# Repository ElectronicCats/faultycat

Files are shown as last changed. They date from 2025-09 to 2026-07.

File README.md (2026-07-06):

# Faulty Cat

> ## Firmware and host tools have moved
>
> This repository now holds the **hardware design** only. The
> firmware (v2, a from-scratch rewrite for the existing FaultyCat
> v2.x hardware) has moved to
> [FaultyCat-Firmware](https://github.com/ElectronicCats/FaultyCat-Firmware),
> and the Python host CLI/TUI (`faultycmd`) has moved to
> [faultycat-TUI](https://github.com/ElectronicCats/faultycat-TUI/).
> See the **Firmware Repository** and **Python Tools Repository**
> sections below.

Faulty Cat is a low-cost Electromagnetic Fault Injection (EMFI) tool, designed specifically for self-study and hobbiest research.

<a href="https://github.com/ElectronicCats/FaultyCat/wiki">
  <p align="center">
  
    </p>
</a>

<p align=center>
<a href="https://electroniccats.com/store/faulty-cat/">
  
</a>

<a href="https://github.com/ElectronicCats/faultycat/wiki">
  
</a>
</p>

<p align=center>
  Also available at distributors:
</p>
<p align=center>
  <a href="https://labs.ksec.co.uk/product-category/electronic-cat/">
    
  </a>
</p>

Faulty Cat is a high-end Electromagnetic Fault Injection (EMFI) tool a remix of the project [ChipSHOUTER PicoEMP](https://github.com/newaetech/chipshouter-picoemp) design optimization focused in rough order on (1) safe operation, (2) high performance, (3) usability, and finally (4) cost. This results in a tool that covers many use-cases, but may be overkill (and expensive) for many.

> **How the glitching works.** Firmware v3 ships two physical
> fault-injection techniques — **EMFI** (electromagnetic) and
> **Crowbar** (voltage glitching) — each available as **direct**
> single-shot fires or as parameter-swept **Campaigns**. For the
> full breakdown of what each engine does, the parameter matrix
> that differentiates them, and how the four combinations are
> driven from the host tool, see `docs/GLITCHING.md` in the
> [firmware repository](https://github.com/ElectronicCats/FaultyCat-Firmware).

We have created this project in KiCad and looking for alternatives to some components, we have left aside the Raspberry Pico board to use the RP2040 directly in the design. Tested in our laboratory before going on sale, even so, it is a product that must be handled with care, read the instructions for use.

Please **only** use Faulty Cat when you have purchased it from us and control it yourself, with full knowledge of the operation and risks. It is *not* designed for use in professional or educational environments, where tools are expected to meet safety certifications.

**IMPORTANT**: The plastic shield is critical for safe operation. While the output itself is isolated from the input connections, you will still **easily shock yourself** on the exposed high-voltage capacitor and circuitry. **NEVER** operate the device without the shield.

As an open-source project and as a remix of the project [ChipSHOUTER PicoEMP](https://github.com/newaetech/chipshouter-picoemp), it also collects inputs from various community members, and welcomes your contributions!

###  NEW FEATURES AVAILABLE ON V2.1⚡😼

- Voltage glitching.
- Trigger using dedicated pins, available in the new pinout.
- Trigger voltage reference, for more accurate response every time a voltage glitch is attempted to be sent.
- Analog input to monitor the target device’s status during the glitching process.
- JTAG/SWD scanner. **(Firmware v3.0 status: `scan swd` is the only
  scanner verb publicly exposed. JTAG scan, direct JTAG verbs, and
  direct SWD verbs are gated as WIP for v3.1 — see
  `docs/JTAG_INTERNALS.md` in the
  [firmware repository](https://github.com/ElectronicCats/FaultyCat-Firmware)
  for the details.)**

### Two attack engines (EMFI and Crowbar)

Firmware v3 exposes two physical fault-injection techniques (EMFI
and Crowbar voltage glitching) and two operational modes (direct
single-shot fires and Campaign parameter sweeps over delay/width/
power). They compose freely — both engines work in both modes.
The full matrix, wire-protocol routing, and host-CLI map live in
`docs/GLITCHING.md` in the
[firmware repository](https://github.com/ElectronicCats/FaultyCat-Firmware).

## Thanks / Contributors

Faulty Cat based in PicoEMP is a community-focused project, with major contributions from:
* Colin O'Flynn (original HW design, simple Python demo)
* [stacksmashing](https://twitter.com/ghidraninja) (C firmware for full PIO feature set)
* [Lennert Wouters](https://twitter.com/LennertWo) (C improvements, first real demo)
* [@nilswiersma](https://github.com/nilswiersma) (Triggering/C improvements)

## Firmware Repository

The FaultyCat firmware has been moved to a different repository, to
have a better version control, and issue tracking you will find it
here:

https://github.com/ElectronicCats/FaultyCat-Firmware

That repository covers building and flashing the firmware (BOOTSEL
button and magic-baud remote BOOTSEL paths), the release scheme, and
the full architecture / safety / glitching-engine documentation
(`docs/ARCHITECTURE.md`, `docs/SAFETY.md`, `docs/GLITCHING.md`,
`docs/JTAG_INTERNALS.md`, `docs/RELEASES.md`, etc.).

## Python Tools Repository

The `faultycmd` host CLI/TUI has been moved to a different
repository, to have a better version control, and issue tracking you
will find it here:

https://github.com/ElectronicCats/faultycat-TUI/

That repository covers installing and using `faultycmd` (venv setup
on Linux, Windows, macOS, hotkeys, trigger polarity, trigger
timeout).

### Useful References

If you don't know where to start with Electromagnetic Fault Injection (EMFI), you may find a couple of chapters of the [Hardware Hacking Handbook](https://nostarch.com/hardwarehacking) useful.

You can see a demo of PicoEMP being used on a real attack in this [TI CC SimpleLink attack demo](https://github.com/KULeuven-COSIC/SimpleLink-FI/blob/main/notebooks/5_ChipSHOUTER-PicoEMP.ipynb).

**WARNING**: The high voltage will be applied across the SMA connector. If an injection tip (coil) is present, it will absorb most of the power. If you leave the SMA connector open, you will present a high voltage pulse across this SMA and could shock yourself. Do NOT touch the output SMA tip as a general "best practice", and treat the output as if it has a high voltage present.

## How to contribute 
 Contributions are welcome!

Please read the document  [**Contribution Manual**](https://github.com/ElectronicCats/electroniccats-cla/blob/main/electroniccats-contribution-manual.md)  which will show you how to contribute your changes to the project.

✨ Thanks to all our [contributors](https://github.com/ElectronicCats/faultycat/graphs/contributors)! ✨

See [**_Electronic Cats CLA_**](https://github.com/ElectronicCats/electroniccats-cla/blob/main/electroniccats-cla.md) for more information.

See the  [**community code of conduct**](https://github.com/ElectronicCats/electroniccats-cla/blob/main/electroniccats-community-code-of-conduct.md) for a vision of the community we want to build and what we expect from it.

## License

This project FaultyCat is adapted from [ChipSHOUTER PicoEMP](https://github.com/newaetech/chipshouter-picoemp) by [Colin O'Flynn](https://github.com/colinoflynn) is licensed under CC BY-SA 3.0, "FaultyCat" contains modifications such as: porting the project to Kicad, modifying BOM and dimensions is licensed under CC BY-SA 3.0 by ElectronicCats.

Electronic Cats invests time and resources in providing this open-source design. Please support Electronic Cats and open-source hardware by purchasing products from Electronic Cats!

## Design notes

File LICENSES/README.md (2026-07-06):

# LICENSES/

This directory holds:

## The hardware itself

The FaultyCat **hardware** (KiCad project under `/Hardware/`) is
licensed under **CC BY-SA 3.0** by Electronic Cats, as a remix of
ChipSHOUTER PicoEMP by Colin O'Flynn. That license covers the
KiCad/PCB files only; it does **not** apply to the firmware in this
repository, which is BSD-3-Clause.

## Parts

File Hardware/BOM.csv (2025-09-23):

Reference | Value | Datasheet | Footprint | Qty | DNP | LCSC# | Manf# | Proveedor
C1,C3 | 4.7uF |  | Capacitor_SMD:C_0805_2012Metric | 2 |  | C98192 | C2012X5R1H475K125AB | LCSC
C2 | 100nF |  | Capacitor_SMD:C_0603_1608Metric | 1 |  | C30926 | C0603C104K5RACTU | LCSC
C4 | 0.47uF |  | BuggyCat:CAPC6153X500N | 1 |  | C692326 | KRM55TR72J474MH01K | MOUSER
C5,C6 | 10uF |  | Capacitor_SMD:C_0402_1005Metric | 2 |  | C15525 | CL05A106MQ5NUNC | LCSC
C7,C11,C12,C14,C15,C16,C17,C18,C19,C20 | 100nF |  | Capacitor_SMD:C_0402_1005Metric | 10 |  | C131394 |  | LCSC
C8,C10 | 27pF |  | Capacitor_SMD:C_0603_1608Metric | 2 |  | C107045 | C0603C270J5GAC7411 | LCSC
C9,C13 | 1uF |  | Capacitor_SMD:C_0603_1608Metric | 2 |  | C26413 | CL10A105KP8NNNC | LCSC
C21,C22 | 100nF |  | Capacitor_SMD:C_0603_1608Metric | 2 |  | C14663 |  | LCSC
D1,D2,D3,D10 | SM4005PL-TP | https://www.mouser.mx/datasheet/2/258/SM4001PL_SM4007PL_SOD_123FL_-2511365.pdf | Diode_SMD:D_SOD-123F | 4 |  | C437593 | 1N4005 | MOUSER
D4 | MURA160T3G | https://www.diodes.com/assets/Datasheets/ds16008.pdf | Diode_SMD:D_SMA | 1 |  | C85095 | US1J-13-F | MOUSER
D5 | MM3Zxx | https://www.mouser.mx/datasheet/2/308/1/MM3Z9V1B_D-1811445.pdf | Diode_SMD:D_SOD-323F | 1 |  | C263147 | MM3Z18VB | MOUSER
D6 | MBR120 | http://www.onsemi.com/pub_link/Collateral/MBR340-D.PDF | Diode_SMD:D_SOD-123 | 1 |  | C130880 |  | LCSC
D7 | H.V.Detected | https://www.mouser.mx/ProductDetail/Kingbright/APT1608SECK?qs=SxaZfIVsCL3ll9vpt7nTCw%3D%3D | LED_SMD:LED_0603_1608Metric | 1 |  | C157740 | APT1608SECK | LCSC
D8 | Status | https://www.mouser.mx/datasheet/2/216/APT1608CGCK-24002.pdf | LED_SMD:LED_0603_1608Metric | 1 |  | C192666 | APT1608CGCK | LCSC
D9 | Charge On | https://www.mouser.mx/ProductDetail/Kingbright/APT1608SECK?qs=SxaZfIVsCL3ll9vpt7nTCw%3D%3D | LED_SMD:LED_0603_1608Metric | 1 |  | C157740 | APT1608SECK | LCSC
F1 | 0.5A | https://www.mouser.mx/datasheet/2/427/mfuserie-1762582.pdf | Fuse:Fuse_0805_2012Metric | 1 |  | C2649565 | MFU0805FF00500P100 | LCSC
J1 | Antenna | https://www.mouser.mx/datasheet/2/276/3/0732511150_RF_COAX_CONNECTORS-2847622.pdf | BuggyCat:732511150 | 1 |  |  | 73251-1150 | MOUSER
J2 | BG306-02-A-2-0400-L-G | https://www.mouser.mx/datasheet/2/837/BG306-1948788.pdf | BuggyCat:BG30602A20400LG | 1 |  |  | BG306-02-A-2-0400-L-G | MOUSER
J3 | Conn_01x10 | ~ | Connector_PinSocket_2.54mm:PinSocket_1x10_P2.54mm_Vertical | 1 |  | C5116489 | 10-PIN
J4 | Header 2 | ~ | Connector_PinHeader_2.54mm:PinHeader_1x02_P2.54mm_Vertical | 1 | DNP
J5 | Header 4 | ~ | Connector_PinHeader_2.54mm:PinHeader_1x04_P2.54mm_Vertical | 1 | DNP
J6 | Input Power:2x AA Battery | ~ | Connector_PinHeader_2.54mm:PinHeader_1x02_P2.54mm_Vertical | 1 | DNP
J7 | GLITCHER_EN | ~ | Connector_PinSocket_2.54mm:PinSocket_1x02_P2.54mm_Vertical | 1 |  | C7499322 | 2-PIN
J8 | ANALOG_PINS | ~ | Connector_PinSocket_2.54mm:PinSocket_1x02_P2.54mm_Vertical | 1 |  | C7499322 | 2-PIN
J9 | TRIGGER_IN | ~ | Connector_PinSocket_2.54mm:PinSocket_1x02_P2.54mm_Vertical | 1 |  | C7499322 | 2-PIN
J10 | TRIGGER_VREF | ~ | Connector_PinSocket_2.54mm:PinSocket_1x02_P2.54mm_Vertical | 1 |  | C7499322 | 2-PIN
P1 | USB_C_Plug_USB2.0 | https://www.usb.org/sites/default/files/documents/usb_type-c.zip | Connectors:C393939 | 1 |  | C393939 |  | LCSC
Q1,Q2 | AO3422 | http://www.aosmd.com/pdfs/datasheet/AO3400A.pdf | Package_TO_SOT_SMD:SOT-23 | 2 |  | C37130 | AO3422 | Digikey
Q3 | LDA111STR | https://www.mouser.mx/datasheet/2/240/LDA111-1547747.pdf | BuggyCat:SOP254P952X470-6N | 1 |  |  | LDA111STR | MOUSER
Q4 | RGT16BM65DTL | https://fscdn.rohm.com/en/products/databook/datasheet/discrete/igbt/rgt16bm65d-e.pdf | Package_TO_SOT_SMD:TO-252-3_TabPin2 | 1 |  | C3193927 | RGT16BM65DTL | MOUSER
Q5 | DMG3415U-7 | https://www.mouser.mx/datasheet/2/115/ds31735-64958.pdf | Package_TO_SOT_SMD:SOT-23 | 1 |  | C96616 | DMG3415U-7 | LCSC
Q7 | IRLML2502 |  | Package_TO_SOT_SMD:SOT-23 | 1 |  | C5364308 |  | LCSC
Q8 | IRF7807PBF |  | BuggyCat:SOIC-8_SI | 1 |  | C142600 |  | LCSC
R1,R9 | 10R |  | Resistor_SMD:R_0603_1608Metric | 2 |  | C109318 | RC0603FR-0710RL | LCSC
R2,R4 | 5.1K |  | Resistor_SMD:R_0603_1608Metric | 2 |  | C23186 | CRCW06035K10FKEAC | LCSC
R3 | 75R |  | Resistor_SMD:R_0805_2012Metric | 1 |  | C141697 | RC0805FR-0775RL | LCSC
R5,R6,R13,R14,R16 | 1K |  | Resistor_SMD:R_0603_1608Metric | 5 |  | C22548 | RC0603FR-071KL | LCSC
R7 | 22K |  | Resistor_SMD:R_0603_1608Metric | 1 |  | C114065 | RC0603FR-0722KL | LCSC
R8 | 2K |  | Resistor_SMD:R_0805_2012Metric | 1 |  | C114572 | RC0805FR-072KL | LCSC
R10 | 20M |  | Resistor_SMD:R_2010_5025Metric | 1 |  |  | CRMA2010AF20M0FKEF | MOUSER
R11 | 300K |  | BuggyCat:RESC6432X120N | 1 |  |  | 3522300KFT | MOUSER
R12 | 100K |  | Resistor_SMD:R_0603_1608Metric | 1 |  | C100048 |  | LCSC
R15 | 4.7k | ~ | Resistor_SMD:R_0603_1608Metric | 1 |  | C116697 |  | LCSC
R17,R25,R26 | 10K |  | Resistor_SMD:R_0603_1608Metric | 3 |  | C103199 |  | LCSC
R18 | 1k |  | Resistor_SMD:R_0603_1608Metric | 1 |  | C115325 |  | LCSC
R19,R20 | 27 |  | Resistor_SMD:R_0603_1608Metric | 2 |  | C25224 | ERJ-3GEYJ270V | MOUSER
R21 | 10k | ~ | Resistor_SMD:R_0603_1608Metric | 1 |  | C103199 |  | LCSC
R23,R24 | 1R | ~ | Resistor_SMD:R_0603_1608Metric | 2 |  | C140111 |  | LCSC
SW1,SW3,SW6 | TL3305AF260QG | https://www.mouser.mx/datasheet/2/140/TL3305-2065758.pdf | BuggyCat:TL3305AF160QG | 3 |  | C2886902 | TL3305AF260QG | MOUSER
SW2 | ON | https://www.mouser.mx/datasheet/2/240/js-3050885.pdf | chipshouter:OS102011MA1QN1 | 1 |  | C221829 | OS102011MS2QN1 | MOUSER
SW4 | RESET | https://www.mouser.mx/datasheet/2/140/TL3342-2065746.pdf | Button_Switch_SMD:SW_SPST_TL3342 | 1 |  | C318889 | TL3342F450QG | MOUSER
SW5 | BOOT | https://www.mouser.mx/datasheet/2/140/TL3342-2065746.pdf | Button_Switch_SMD:SW_SPST_TL3342 | 1 |  | C318889 | TL3342F450QG | MOUSER
SW7 | SW_SP3T | ~ | BuggyCat:Sw3P1T | 1 |  | C361168 |  | LCSC
T1,T2 | ATB322524 | ~ | BuggyCat:ATB3225240110T000 | 2 |  | C249001 | ATB322524-0110-T000 | MOUSER
U1 | AP2112K-3.3 | https://www.diodes.com/assets/Datasheets/AP7347DQ.pdf | Package_TO_SOT_SMD:SOT-23-5 | 1 |  | C216640 | AP7347DQ-33W5-7 | MOUSER
U2 | W25Q16JV | https://www.mouser.mx/datasheet/2/949/w25q16jv_spi_revg_03222018_plus-1489727.pdf | BuggyCat:W25Q16JVUUIQ | 1 |  |  | W25Q16JVUUIQ TR | MOUSER
U3 | RP2040 | https://www.mouser.mx/datasheet/2/630/hardware_design_with_rp2040-2904726.pdf | BuggyCat:RP2040-QFN-56 | 1 |  | C2040 | RPI Chip RP2040-7-500 | LCSC
U4 | TXS0108EPW | www.ti.com/lit/ds/symlink/txs0108e.pdf | Package_SO:TSSOP-20_4.4x6.5mm_P0.65mm | 1 |  | C1021790 |  | LCSC
U5 | TLV75718PDBV | https://www.ti.com/lit/ds/symlink/tlv757p.pdf | Package_TO_SOT_SMD:SOT-23-5 | 1 |  | C507270 |  | LCSC
U6 | SN74LVC1T45DBV | http://www.ti.com/lit/ds/symlink/sn74lvc1t45.pdf | Package_TO_SOT_SMD:SOT-23-6 | 1 |  | C7843 |  | LCSC
Y1 | 12Mhz | https://www.mouser.mx/datasheet/2/96/008-0360-0-786290.pdf | Crystal:Crystal_SMD_5032-2Pin_5.0x3.2mm | 1 |  |  | 445I23D12M00000 | MOUSER

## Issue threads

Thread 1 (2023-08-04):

License Violations

colinoflynn, 2023-08-04:
Hello - this project is currently in violation of CC-SA-3.0 license that PicoEMP is released under and this project heavily remixed. Please rectify this ASAP.

The license requires you to:

Attribution — You must give [appropriate credit](https://creativecommons.org/licenses/by-sa/3.0/#), provide a link to the license, and [indicate if changes were made](https://creativecommons.org/licenses/by-sa/3.0/#). You may do so in any reasonable manner, but not in any way that suggests the licensor endorses you or your use.

ShareAlike — If you remix, transform, or build upon the material, you must distribute your contributions under the [same license](https://creativecommons.org/licenses/by-sa/3.0/#) as the original.

The biggest issue here is reusing the majority of the text in the description without correctly attributing back to PicoEMP, along with similar issues on design (at least design is more of a remix than direct copy). But the remix of PicoEMP into FaultyCat should be a clear step, but it's very muddled right now. The remixed material should be shared under the same license per CC-SA-3.0.

This is required as it's possible/likely that FaultyCat is itself remixed in the future, and if that happens someone may not realize they were actually borrowing from PicoEMP. The link between all the projects should be clear for future users.

Thanks!

sabas1080, 2023-08-04:
Hello @colinoflynn

First of all, apologies for not executing the license correctly. We want to clarify that our intention was not to take the project's appropriation, we have made the corresponding changes, and we await your feedback.
Thank you so much for doing this great project. We admire your work and hope you like the changes we have made and the next ones we make to your project.

Best regards,

colinoflynn, 2023-08-04:
Thanks for quick fix, appreciate it & keeping the sharing spirit of FOSS alive! Looks like a nice mix (and no more broken battery wires ;-) ), hope you get a chance to let people enjoy EMFI at DC!

Closed 2023-08-04.

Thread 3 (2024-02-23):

Add schematic in pdf too

mrx23dot, 2024-02-23:

Marcelol52, 2024-02-23:
Hi, we will consider adding the file to the Wiki for later revisions. We cannot add it on the repository because it is not a binnary file and it would not be updated automatically by git. You can always check the schematics usig KiCAD on any operating system from the files found on the hardware section of the repository. I have shared the PDF with you attached in this message. Thank your for your suggestion and your preference.

[FaultyCat.pdf](https://github.com/ElectronicCats/faultycat/files/14388274/FaultyCat.pdf)

Closed 2024-02-23.

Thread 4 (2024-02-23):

Details on differences from PicoEMP

mrx23dot, 2024-02-23:
From current description it's not clear enough what are the benefits compared to PicoEMP:

 (1) safe operation, (2) high performance, (3) usability, and finally (4) cost.

e.g. how pulse is different.

Also how it's optimized for cost when price is 2x of PicoEMP

xpeqex, 2024-02-23:
Hi @mrx23dot

Thank you for the feedback. While FaultyCat is based on PicoEMP we were looking on improving the product itself.

In any case, I agree that more information should be added to better clarify the improvements in FaultyCat.

Here is a short description to the points you are mentioning that will be later updated in the wiki:
1. **_Safe operation_**. This refers to the use of commands to remotely operate FaultyCat, the enclosure that protects the user from a discharge of high-power components and the automatic shutdown function.
2. **_High Performance_**. Unlike other EMFI tools, FultyCat allows you to trigger the EMFI with a shorter charging time, using only three AA batteries and with a high voltage output through the _business end_, around 200V according to our tests.
3. **_Usability_** . FaultyCat **is a plug and play device, no need to solder and with firmware preloaded**. In any case, we work to provide further documentation and support. So you do not have only a product but a service too backing FaultyCat.
4. **_Cost_** . It is important to highlight the performance of FaultyCat against other EMFI device and the fact we take care of all the details of the board, from the manufacture process, testing to the provide support.

With this being said, FaultyCat as PicoEMP is an open source project, meaning that anyone can use the available information to improve and/or modify the product itself creating a more specialized product that fits your needs.

Hope this information is helpful. Be assure we will add this to our documentation, thank you for brining it to our attention.

Feel free to share with us any other feedback or queries!

Closed 2024-02-23.

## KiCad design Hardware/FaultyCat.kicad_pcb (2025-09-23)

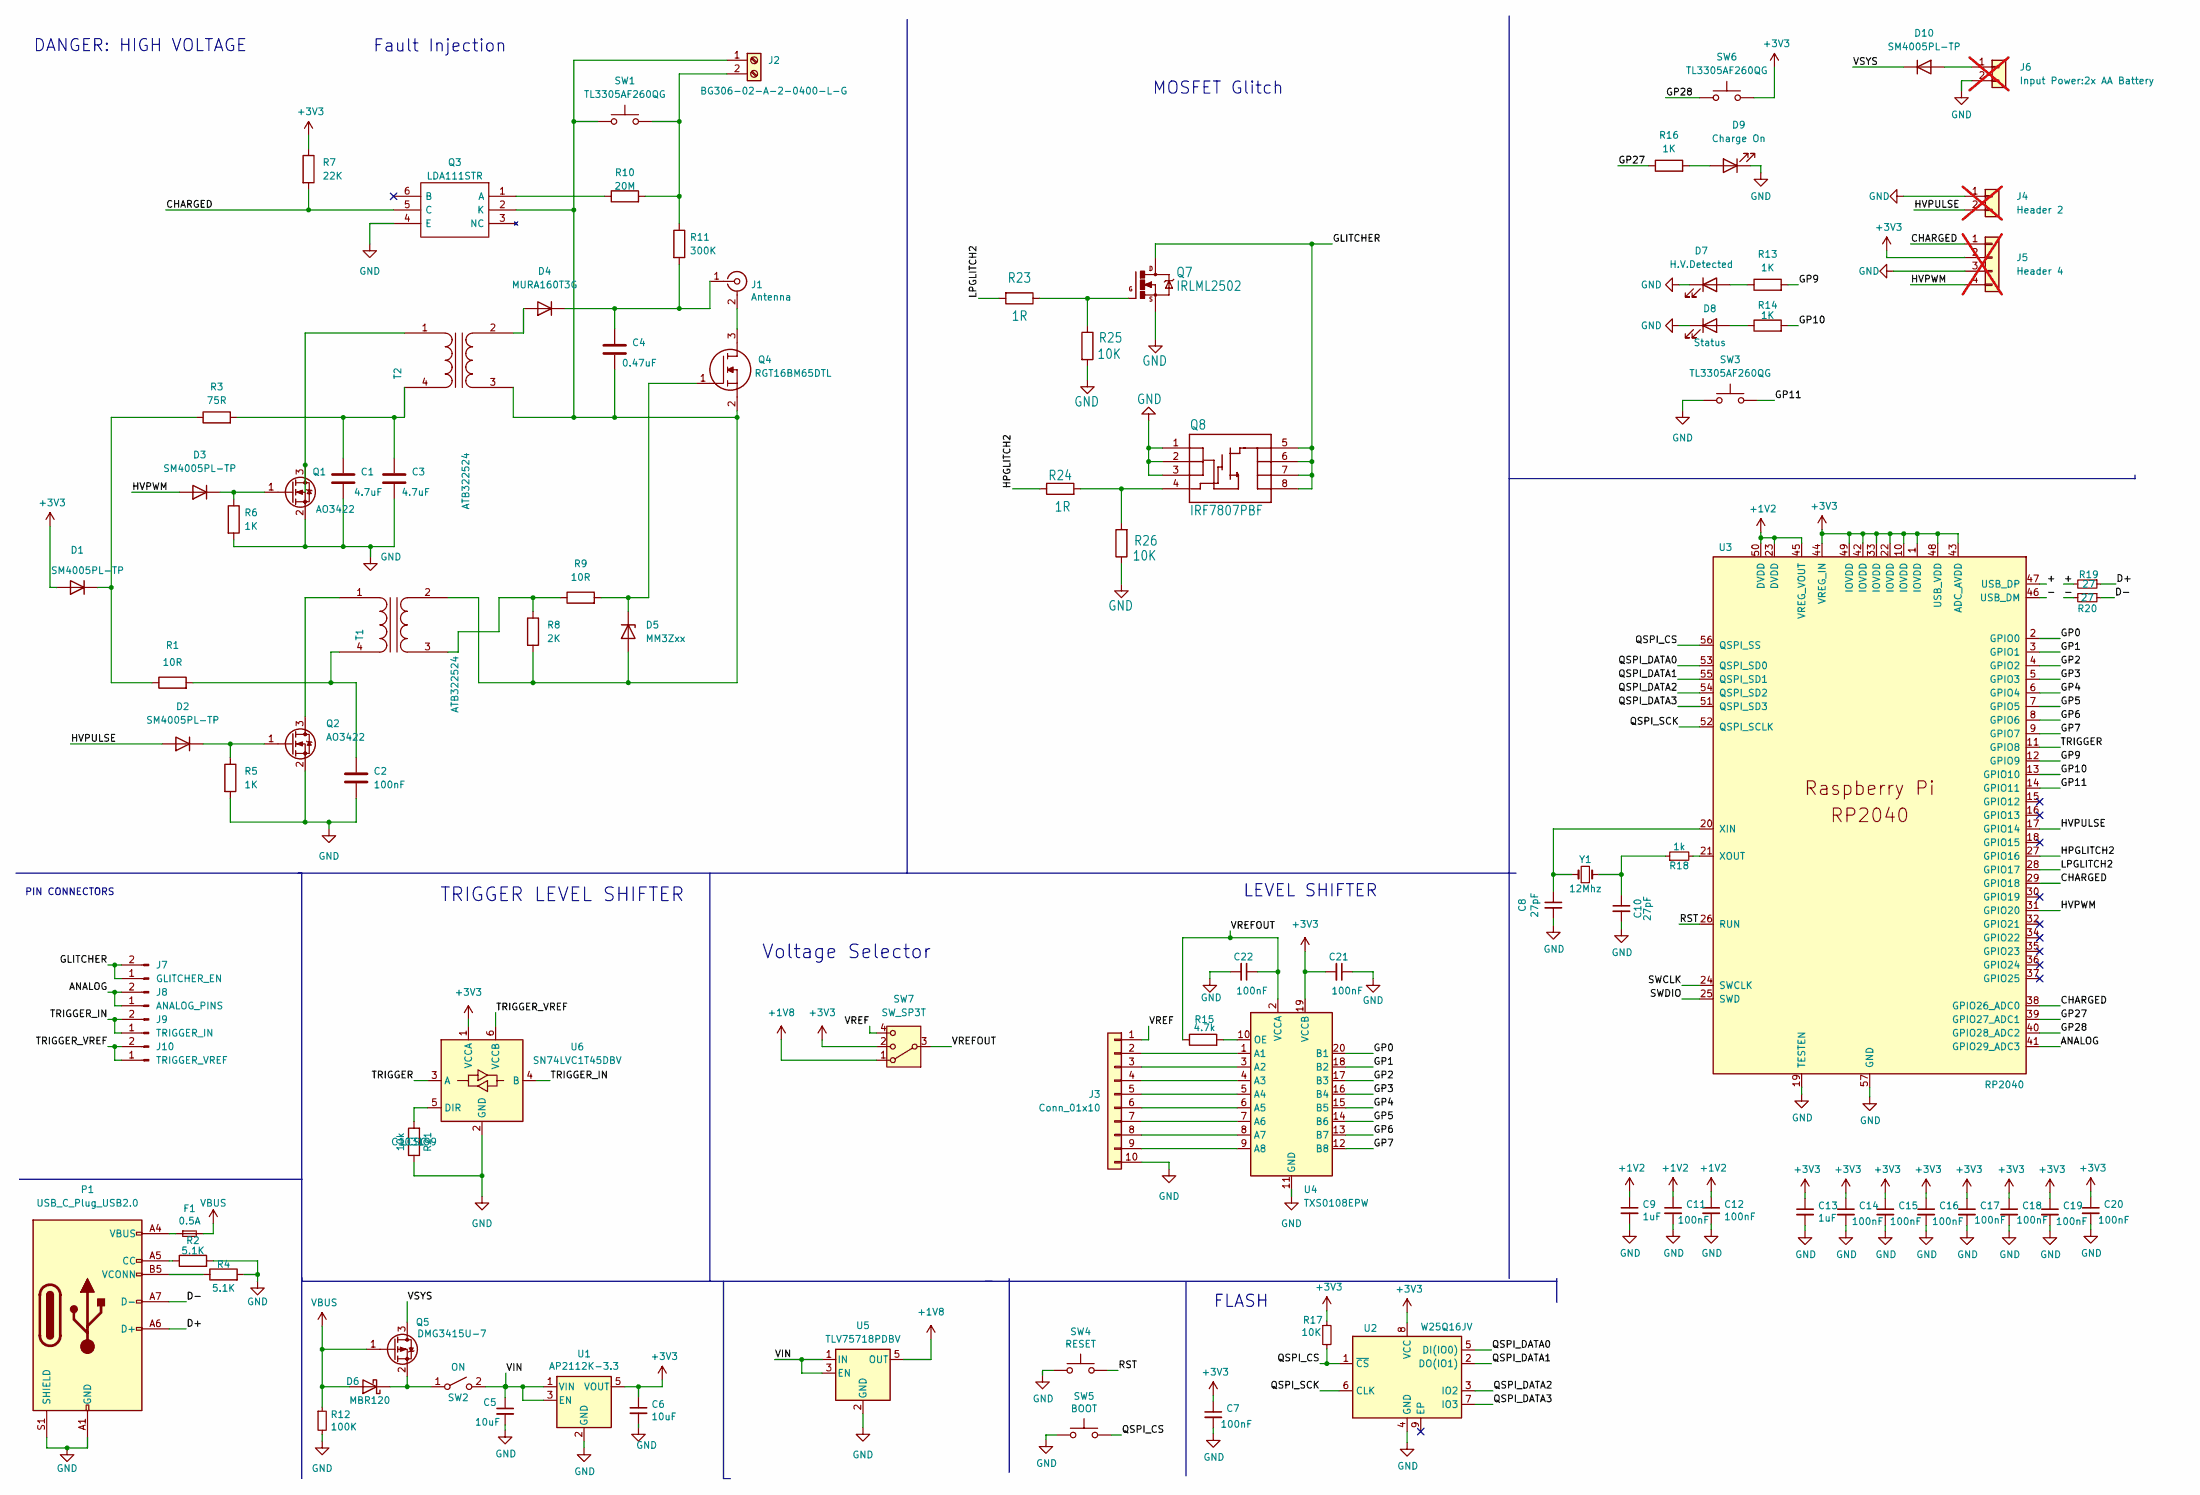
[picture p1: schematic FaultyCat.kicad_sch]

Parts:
C1, C3: 4.7uF; C_0805_2012Metric; LCSC# C98192
C2: 100nF; C_0603_1608Metric; LCSC# C30926
C4: 0.47uF; CAPC6153X500N; LCSC# C692326
C5, C6: 10uF; C_0402_1005Metric; LCSC# C15525
C7, C11, C12, C14, C15, C16, C17, C18, C19, C20: 100nF; C_0402_1005Metric; LCSC# C131394
C8, C10: 27pF; C_0603_1608Metric; LCSC# C107045
C9, C13: 1uF; C_0603_1608Metric; LCSC# C26413
C21, C22: 100nF; C_0603_1608Metric; LCSC# C14663
D1, D2, D3, D10: SM4005PL-TP; D_SOD-123F; LCSC# C437593
D4: MURA160T3G; D_SMA; LCSC# C85095
D5: MM3Zxx; D_SOD-323F; LCSC# C263147
D6: MBR120; D_SOD-123; LCSC# C130880
D7: H.V.Detected; LED_0603_1608Metric; LCSC# C157740
D8: Status; LED_0603_1608Metric; LCSC# C192666
D9: Charge On; LED_0603_1608Metric; LCSC# C157740
F1: 0.5A; Fuse_0805_2012Metric; LCSC# C2649565
J1: Antenna; 732511150
J2: BG306-02-A-2-0400-L-G; BG30602A20400LG
J3: Conn_01x10; PinSocket_1x10_P2.54mm_Vertical; LCSC# C5116489
J4: Header 2; PinHeader_1x02_P2.54mm_Vertical; not fitted
J5: Header 4; PinHeader_1x04_P2.54mm_Vertical; not fitted
J6: Input Power:2x AA Battery; PinHeader_1x02_P2.54mm_Vertical; not fitted
J7: GLITCHER_EN; PinSocket_1x02_P2.54mm_Vertical; LCSC# C7499322
J8: ANALOG_PINS; PinSocket_1x02_P2.54mm_Vertical; LCSC# C7499322
J9: TRIGGER_IN; PinSocket_1x02_P2.54mm_Vertical; LCSC# C7499322
J10: TRIGGER_VREF; PinSocket_1x02_P2.54mm_Vertical; LCSC# C7499322
P1: USB_C_Plug_USB2.0; C393939; LCSC# C393939
Q1, Q2: AO3422; SOT-23; LCSC# C37130
Q3: LDA111STR; SOP254P952X470-6N
Q4: RGT16BM65DTL; TO-252-3_TabPin2; LCSC# C3193927
Q5: DMG3415U-7; SOT-23; LCSC# C96616
Q7: IRLML2502; SOT-23; LCSC# C5364308
Q8: IRF7807PBF; SOIC-8_SI; LCSC# C142600
R1, R9: 10R; R_0603_1608Metric; LCSC# C109318
R2, R4: 5.1K; R_0603_1608Metric; LCSC# C23186
R3: 75R; R_0805_2012Metric; LCSC# C141697
R5, R6, R13, R14, R16: 1K; R_0603_1608Metric; LCSC# C22548
R7: 22K; R_0603_1608Metric; LCSC# C114065
R8: 2K; R_0805_2012Metric; LCSC# C114572
R10: 20M; R_2010_5025Metric
R11: 300K; RESC6432X120N
R12: 100K; R_0603_1608Metric; LCSC# C100048
R15: 4.7k; R_0603_1608Metric; LCSC# C116697
R17, R25, R26: 10K; R_0603_1608Metric; LCSC# C103199
R18: 1k; R_0603_1608Metric; LCSC# C115325
R19, R20: 27; R_0603_1608Metric; LCSC# C25224
R21: 10k; R_0603_1608Metric; LCSC# C103199
R23, R24: 1R; R_0603_1608Metric; LCSC# C140111
SW1, SW3, SW6: TL3305AF260QG; TL3305AF160QG; LCSC# C2886902
SW2: ON; OS102011MA1QN1; LCSC# C221829
SW4: RESET; SW_SPST_TL3342; LCSC# C318889
SW5: BOOT; SW_SPST_TL3342; LCSC# C318889
SW7: SW_SP3T; Sw3P1T; LCSC# C361168
T1, T2: ATB322524; ATB3225240110T000; LCSC# C249001
U1: AP2112K-3.3; SOT-23-5; LCSC# C216640
U2: W25Q16JV; W25Q16JVUUIQ
U3: RP2040; RP2040-QFN-56; LCSC# C2040
U4: TXS0108EPW; TSSOP-20_4.4x6.5mm_P0.65mm; LCSC# C1021790
U5: TLV75718PDBV; SOT-23-5; LCSC# C507270
U6: SN74LVC1T45DBV; SOT-23-6; LCSC# C7843
Y1: 12Mhz; Crystal_SMD_5032-2Pin_5.0x3.2mm

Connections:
+1V2: C9.1, C11.1, C12.1, U3.23 (DVDD), U3.45 (VREG_VOUT), U3.50 (DVDD)
+1V8: SW7.1, U5.5 (OUT); also elsewhere on the board
+3V3: C6.1, C7.1, C13.1, C14.1, C15.1, C16.1, C17.1, C18.1, C19.1, C20.1, C21.2, D1.2 (A), J5.2, R7.1, R17.1, SW6.2, SW7.2, U1.5 (VOUT), U2.8 (VCC), U3.1 (IOVDD), U3.10 (IOVDD), U3.22 (IOVDD), U3.33 (IOVDD), U3.42 (IOVDD), U3.43 (ADC_AVDD), U3.44 (VREG_IN), U3.48 (USB_VDD), U3.49 (IOVDD), U4.19 (VCCB), U6.1 (VCCA)
/+: R19.2, U3.47 (USB_DP)
/-: R20.2, U3.46 (USB_DM)
/ANALOG: J8.1, J8.2, U3.41 (GPIO29_ADC3)
/CHARGED: J5.1, Q3.5 (C), R7.2, U3.29 (GPIO18), U3.38 (GPIO26_ADC0)
/D+: P1.A6 (D+), R19.1
/D-: P1.A7 (D-), R20.1
/GLITCHER: J7.1, J7.2, Q7.3 (D), Q8.5 (D@4), Q8.6 (D@3), Q8.7 (D@2), Q8.8 (D@1)
/GP0: U3.2 (GPIO0), U4.20 (B1)
/GP1: U3.3 (GPIO1), U4.18 (B2)
/GP2: U3.4 (GPIO2), U4.17 (B3)
/GP3: U3.5 (GPIO3), U4.16 (B4)
/GP4: U3.6 (GPIO4), U4.15 (B5)
/GP5: U3.7 (GPIO5), U4.14 (B6)
/GP6: U3.8 (GPIO6), U4.13 (B7)
/GP7: U3.9 (GPIO7), U4.12 (B8)
/GP9: R13.2, U3.12 (GPIO9)
/GP10: R14.2, U3.13 (GPIO10)
/GP11: SW3.2, U3.14 (GPIO11)
/GP27: R16.1, U3.39 (GPIO27_ADC1)
/GP28: SW6.1, U3.40 (GPIO28_ADC2)
/HPGLITCH2: R24.1, U3.27 (GPIO16)
/HVPULSE: D2.2 (A), J4.2, U3.17 (GPIO14)
/HVPWM: D3.2 (A), J5.4, U3.31 (GPIO20)
/LPGLITCH2: R23.2, U3.28 (GPIO17)
/QSPI_CS: R17.2, SW5.2, U2.1 (~CS), U3.56 (QSPI_SS)
/QSPI_DATA0: U2.5 (DI(IO0)), U3.53 (QSPI_SD0)
/QSPI_DATA1: U2.2 (DO(IO1)), U3.55 (QSPI_SD1)
/QSPI_DATA2: U2.3 (IO2), U3.54 (QSPI_SD2)
/QSPI_DATA3: U2.7 (IO3), U3.51 (QSPI_SD3)
/QSPI_SCK: U2.6 (CLK), U3.52 (QSPI_SCLK)
/RST: SW4.2, U3.26 (RUN)
/SWCLK: U3.24 (SWCLK)
/SWDIO: U3.25 (SWD)
/TRIGGER: U3.11 (GPIO8), U6.3 (A)
/TRIGGER_IN: J9.1, J9.2, U6.4 (B)
/TRIGGER_VREF: J10.1, J10.2, U6.6 (VCCB)
/VIN: C5.1, SW2.2 (B), U1.1 (VIN), U1.3 (EN), U5.1 (IN), U5.3 (EN); also elsewhere on the board
/VREF: J3.1, SW7.4
/VREFOUT: C22.1, R15.1, SW7.3, U4.2 (VCCA)
/VSYS: D10.1 (K), Q5.3 (D)
GND: C1.2, C2.2, C3.2, C5.2, C6.2, C7.2, C8.2, C9.2, C10.2, C11.2, C12.2, C13.2, C14.2, C15.2, C16.2, C17.2, C18.2, C19.2, C20.2, C21.1, C22.2, D7.1 (K), D8.1 (K), D9.1 (K), J3.10, J4.1, J5.3, J6.2, P1.A1 (GND), P1.A12 (GND), P1.B1 (GND), P1.B12 (GND), P1.S1 (SHIELD), Q1.2 (S), Q2.2 (S), Q3.4 (E), Q7.2 (S), Q8.1 (S@1), Q8.2 (S@2), Q8.3 (S@3), R2.2, R4.2, R5.2, R6.2, R12.2, R21.1, R25.2, R26.1, SW3.1, SW4.1, SW5.1, U1.2 (GND), U2.4 (GND), U3.19 (TESTEN), U3.57 (GND), U4.11 (GND), U5.2 (GND), U6.2 (GND); also elsewhere on the board
unnamed: C10.1, R18.1, Y1.2
unnamed: D1.1 (K), R1.1, R3.1
unnamed: D2.1 (K), Q2.1 (G), R5.1
unnamed: D3.1 (K), Q1.1 (G), R6.1
unnamed: D4.2 (A), T2.2 (SA)
unnamed: C4.1, D4.1 (K), J1.1 (In), R11.2
unnamed: C4.2, D5.2 (A), J2.1, Q3.2 (K), Q4.2, R8.2, SW1.1, T1.2 (SA), T2.3 (SB)
unnamed: D5.1 (K), Q4.1, R9.2
unnamed: D6.1 (K), Q5.2 (S), SW2.1 (A)
unnamed: D7.2 (A), R13.1
unnamed: D8.2 (A), R14.1
unnamed: D9.2 (A), R16.2
unnamed: D10.2 (A), J6.1
unnamed: F1.1, P1.A4 (VBUS), P1.A9 (VBUS), P1.B4 (VBUS), P1.B9 (VBUS)
unnamed: J1.2 (Ext), Q4.3
unnamed: J2.2, R10.2, R11.1, SW1.2
unnamed: J3.2, U4.1 (A1)
unnamed: J3.3, U4.3 (A2)
unnamed: J3.4, U4.4 (A3)
unnamed: J3.5, U4.5 (A4)
unnamed: J3.6, U4.6 (A5)
unnamed: J3.7, U4.7 (A6)
unnamed: J3.8, U4.8 (A7)
unnamed: J3.9, U4.9 (A8)
unnamed: P1.A5 (CC), R2.1
unnamed: P1.B5 (VCONN), R4.1
unnamed: Q1.3 (D), T2.1 (AB)
unnamed: Q2.3 (D), T1.1 (AB)
unnamed: Q3.1 (A), R10.1
unnamed: Q7.1 (G), R23.1, R25.1
unnamed: Q8.4 (G), R24.2, R26.2
unnamed: C2.1, R1.2, T1.4 (AA)
unnamed: R8.1, R9.1, T1.3 (SB)
unnamed: C1.1, C3.1, R3.2, T2.4 (AA)
unnamed: C8.1, U3.20 (XIN), Y1.1
unnamed: R18.2, U3.21 (XOUT)
unnamed: R15.2, U4.10 (OE)
unnamed: R21.2, U6.5 (DIR)
VBUS: D6.2 (A), F1.2, Q5.1 (G), R12.1

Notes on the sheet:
Voltage Selector
FLASH
TRIGGER LEVEL SHIFTER
MOSFET Glitch
DANGER: HIGH VOLTAGE
PIN CONNECTORS
LEVEL SHIFTER
Fault Injection

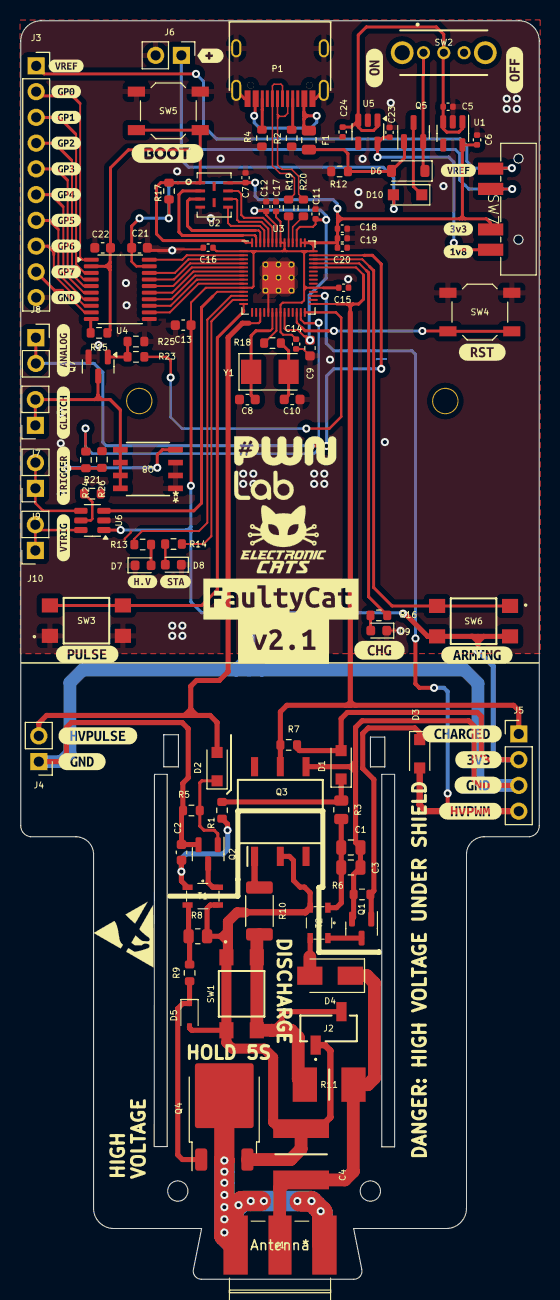
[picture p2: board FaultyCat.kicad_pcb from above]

Board: 2 copper layers, 51.2 x 124.2 mm, 129 parts (0 on the bottom side), 81 nets.

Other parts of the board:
C23, C24: 10uF; C_0402_1005Metric
kibuzzard-67A4D63C: G***; kibuzzard-67A4D63C
kibuzzard-67A4D65E: G***; kibuzzard-67A4D65E
kibuzzard-67A4D80D: G***; kibuzzard-67A4D80D
kibuzzard-67A4D86D: G***; kibuzzard-67A4D86D
kibuzzard-67A4D88F: G***; kibuzzard-67A4D88F
kibuzzard-67A4D93E: G***; kibuzzard-67A4D93E
kibuzzard-67A4D642: G***; kibuzzard-67A4D642
kibuzzard-67A4D648: G***; kibuzzard-67A4D648
kibuzzard-67A4D805: G***; kibuzzard-67A4D805
kibuzzard-67A4D873: G***; kibuzzard-67A4D873
kibuzzard-67A4D879: G***; kibuzzard-67A4D879
kibuzzard-67A4D880: G***; kibuzzard-67A4D880
kibuzzard-67A4D886: G***; kibuzzard-67A4D886
kibuzzard-67A4D896: G***; kibuzzard-67A4D896
kibuzzard-67AA52CA: G***; kibuzzard-67AA52CA
kibuzzard-67AA52D2: G***; kibuzzard-67AA52D2
kibuzzard-642DF5C4: G***; kibuzzard-642DF5C4
kibuzzard-642DF578: G***; kibuzzard-642DF578
kibuzzard-642E0AC9: G***; kibuzzard-642E0AC9
kibuzzard-642E0AD5: G***; kibuzzard-642E0AD5
kibuzzard-642E0AF5: G***; kibuzzard-642E0AF5
kibuzzard-642E0B26: G***; kibuzzard-642E0B26
kibuzzard-642E0B82: G***; kibuzzard-642E0B82
kibuzzard-642E0B91: G***; kibuzzard-642E0B91
kibuzzard-642E11AF: G***; kibuzzard-642E11AF
kibuzzard-642F0B74: G***; kibuzzard-642F0B74
kibuzzard-681E47A0: G***; kibuzzard-681E47A0
kibuzzard-681E47A5: G***; kibuzzard-681E47A5
kibuzzard-681E4798: G***; kibuzzard-681E4798
kibuzzard-6797D18C: G***; kibuzzard-6797D18C
kibuzzard-64767B55: G***; kibuzzard-64767B55
kibuzzard-68509CA3: G***; kibuzzard-68509CA3
kibuzzard-647546A8: G***; kibuzzard-647546A8
kibuzzard-647546B9: G***; kibuzzard-647546B9
kibuzzard-6475468D: G***; kibuzzard-6475468D

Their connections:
+1V8: C23.1; also elsewhere on the board
/VIN: C24.1; also elsewhere on the board
GND: C23.2, C24.2; also elsewhere on the board

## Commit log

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2023-04-03 Renaming of all files from chipshoutercat to buggycat
    [BuggyCat.kicad_pcb, BuggyCat.kicad_sch]
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2025-02-10 fix(hw): move labels
    [FaultyCat.kicad_pcb]
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2025-05-13 fix(hw): remove manuf# from P1
    [FaultyCat.kicad_sch]
2025-06-09 fix(hw): move components
    [FaultyCat.kicad_pcb]
2025-06-26 fix(hw): change switch orientation
    [FaultyCat.kicad_pcb]
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2026-04-23 docs(v3): ARCHITECTURE + HARDWARE_V2 + PORTING + README rewrite banner
    F0 commit 4/5. First-cut documentation with the data confirmed during
    F0 research (2026-04-23):
    docs/ARCHITECTURE.md
    Layered view of the v3 firmware (hal → drivers → services → usb →
    apps), USB composite table with all 16/16 endpoints accounted for,
    SWD-bus arbitration policy (finalized in F9), and how faultycmd-rs
    sits on top.
    docs/HARDWARE_V2.md
    Authoritative pinout map for FaultyCat HW v2.x (v2.2 is the shipped
    version; v2.1 → v2.2 changed labels only). Derived from
    firmware/c/board_config.h, glitcher.c, and the KiCad schematic.
    Key confirmations from the maintainer this session:
    * scann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
2026-04-23 docs(plan): consolidate F0 resolutions + add phase-tracking skill
    Post-F0 housekeeping. Does not belong to any of the 5 F0 commits and
    does not block the v3.0-f0 tag — but lands with F0 so the plan and
    the Claude-Code skill reflect the same reality.
    FAULTYCAT_REFACTOR_PLAN.md
    §1 clarification: HW v2.2 is the only production revision (v2.1 →
    v2.2 = label change only, no nets).
    §2 table correction: raspberrypi/debugprobe is MIT, not BSD-3, and
    hextreeio/faultier is verified "NONE" (all rights reserved) →
    reference-only, marked EXCLUDE_FROM_ALL.
    §12 rewritten as "Decisiones resueltas en F0 (2026-04-23)":
    every item now shows its resolved value (branch rewrite/v3,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
2026-04-23 fix(v3): F0 blink on GP10 (real STATUS LED on v2.x) — NOT GP25
    F0 hotfix, lands before the v3.0-f0 tag.
    Root cause: the legacy firmware/c/board_config.h declares
    `PIN_LED_STATUS = 25`, which is correct when targeting the Raspberry
    Pi Pico module (GP25 is the Pico's onboard LED). But FaultyCat v2.x
    mounts the RP2040 **directly** on its own PCB — there is no Pico
    module and GP25 is not routed to any LED. The initial F0 blink
    flashed fine but produced no visible output on a physical v2.2
    board (verified by the maintainer 2026-04-23).
    Fix:
    apps/faultycat_fw/main.c
    STATUS_LED_PIN 25 → 10. The real STATUS LED on v2.x is GP10.
    (Cross-check: firmware/c/glitcher/glitcher.c line 23 a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
2026-04-23 feat(F1): HAL gpio + time — portable API, RP2040 impl, native fakes, 10 unit tests
    F1 commit 2/4. Extracts a thin, portable HAL layer so drivers and apps
    never touch pico-sdk APIs directly, and gives us host-side fakes so
    unit tests run natively without any MCU.
    Headers (`hal/include/hal/`)
    gpio.h — init / put / get / set_pulls. Minimal surface; drive
    strength and alt-functions arrive when a driver asks for
    them in F2+.
    time.h — sleep_ms, now_ms, now_us. 32-bit counters (wrap at 49.7d /
    71.6m respectively) — longer horizons land when needed.
    pio.h dma.h adc.h pwm.h usb.h — placeholder headers that trip
    `#error` on include. Forces u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
2026-04-23 feat(F1): rewrite F0 blink on top of the HAL
    F1 commit 3/4.
    No longer includes pico/stdlib.h or calls gpio_init/gpio_set_dir/
    gpio_put/sleep_ms. The file now compiles against hal/gpio.h and
    hal/time.h only. This is the template for every future app: apps
    assemble services, services assemble drivers, drivers talk to the
    HAL. Nothing below the HAL reaches sideways into pico-sdk.
    apps/faultycat_fw/CMakeLists.txt
    target_link_libraries(faultycat PRIVATE pico_stdlib)
    → target_link_libraries(faultycat PRIVATE hal_rp2040)
    hal_rp2040 transitively pulls pico_stdlib and hardware_gpio.
    Verification:
    * arm-none-eabi-nm on main.c.o shows only hal_gpio_init,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
2026-04-23 ci(F1): add host-tests job alongside the UF2 build
    F1 commit 4/4 — closes F1 (pending the physical blink checkpoint).
    Workflow now runs two parallel jobs on every push to rewrite/v3 and
    on every PR:
    host-tests
    ubuntu-24.04, cmake + ninja only (no arm toolchain).
    Runs `cmake --preset host-tests`, `cmake --build …`,
    and `ctest --preset host-tests --output-on-failure`.
    Fails fast if any Unity test fails.
    build (unchanged from F0)
    ubuntu-24.04, gcc-arm-none-eabi.
    Builds fw-release UF2 + ELF, uploads as 30-day artifact.
    Keeping both in the same file (firmware.yml) means a single workflow
    status covers the whole repo: if either job is red, the commit is not
    read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
2026-04-23 docs(skill): update phase-tracking skill to reflect v3.0-f1 closure
    Post-F1 housekeeping. Lands after the tag, not inside F1's scope.
    .claude/skills/faultycat-fase-actual/SKILL.md
    State moved from "F0 closed, awaiting tag" to "F1 closed at
    v3.0-f1, F2 next". Summarizes both completed phases (F0 + F1 with
    commit SHAs), lists the active vendored submodules (now six,
    including Unity), documents the current HAL surface (gpio + time
    implemented, the rest as #error stubs), and primes F2 scope —
    the first phase that can touch the HV domain, so the safety-gate
    rule moves from "documented but dormant" to "actively enforced."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
2026-04-23 feat(F2a-1): drivers/ui_leds — 3 LEDs + HV hysteresis + board_v2.h
    F2a commit 1/5. First HW driver. Ports the LED logic proven in the
    legacy firmware (firmware/c/picoemp.c) onto the new layered layout,
    with proper unit-test coverage via the HAL fake.
    drivers/include/board_v2.h (new)
    Single source of truth for every FaultyCat v2.x pin mapping.
    Supersedes the legacy firmware/c/board_config.h, which carried
    Pico-module assumptions (PIN_LED_STATUS=25, no LED on v2.x) and
    stale faultier relics (PIN_EXT1=27 collided with charge LED).
    BOARD_GP_* constants land here as each driver in F2 lifts them
    into scope. Documents the "no hardware voltage mux on v2.2"
    confirmation from the main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
2026-04-23 feat(F2a-2): drivers/ui_buttons + USB-serial diag loop
    F2a commit 2/5. Second driver, plus the F2 diagnostic path that lets
    the maintainer verify driver behaviour from a serial terminal.
    drivers/ui_buttons/
    Public API (ui_buttons.h):
    ui_buttons_init() — input + correct internal pull
    per button (ARM=pulldown,
    PULSE=pullup).
    ui_buttons_is_pressed(btn) — polarity-normalized read. Both
    buttons return true when
    physically pressed, regardless
    of whether they're wired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
2026-04-23 feat(F2a-3): drivers/target_monitor + lift hal/adc stub
    F2a commit 3/5. Promotes hal/adc.h from the F1 `#error` placeholder to
    a real API and wires in the target-monitor analog input on GP29.
    hal/
    include/hal/adc.h — minimal surface:
    hal_adc_init() — enable the ADC peripheral
    hal_adc_channel_enable(ch) — route the backing GPIO
    hal_adc_read(ch) — select + one-shot 12-bit read
    src/rp2040/adc.c — pico-sdk hardware_adc wrapper. Maps channel N
    to GP(26+N); channel 4 (internal temp sensor) is intentionally
    not exposed — add when a driver needs it.
    CMakeLists.txt — hal_rp2040 now links hardware_adc and compiles
    the ne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
2026-04-23 feat(F2a-5): drivers/ext_trigger — external trigger in on GP8 — closes F2a
    F2a commit 5/5. Last of the low-risk drivers; after this we tag
    v3.0-f2a and move to F2b (HV domain).
    drivers/ext_trigger/
    Public API (ext_trigger.h):
    ext_trigger_init(pull) — GP8 as input with optional pull
    ext_trigger_set_pull(pull) — re-pull without re-init
    ext_trigger_level() — raw GPIO level
    Pull enum: NONE / UP / DOWN. Scope ends at "tell me the level"; all
    edge/level/pulse/serial semantics (RISING, FALLING, HIGH, LOW,
    PULSE_POSITIVE, PULSE_NEGATIVE, SERIAL pattern from the legacy
    glitcher) belong to the glitch engine service in F5.
    tests/test_ext_trigger.c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
2026-04-23 docs(skill): update phase-tracking skill to reflect v3.0-f2a closure
    Post-F2a housekeeping. After the tag, before F2b starts.
    State moves from "F1 closed → F2 next" to "F2a closed → F2b next
    (drivers HV, SAFETY GATE ACTIVE)".
    Lists all 5 F2a drivers + the board_v2.h single-source-of-truth.
    Notes the confirmed facts picked up during F2a physical verification:
    * ADC GP29 is direct (no divider) — F4 service will not need a
    scaling factor.
    * pico-sdk stdio_usb needs DTR asserted to emit output; plain
    `cat /dev/ttyACM?` won't show the diag stream.
    * all 41 Unity cases pass across 7 binaries.
    Adds the F2b-specif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
2026-04-23 feat(F2b-2): drivers/voltage_mux — stub with #error (no HW mux on v2.x)
    F2b commit 2/4. Trivial commit by design: v2.2 has no voltage
    multiplexer component, so the architectural slot stays as a stub
    with a hard #error and a README explaining why.
    drivers/voltage_mux/voltage_mux.h
    Single-line file after the doc comment:
    #error "drivers/voltage_mux is a stub — FaultyCat HW v2.x has no
    voltage mux. Do not include."
    Any accidental `#include "voltage_mux.h"` now fails the compile
    with a clear message instead of producing a link error later.
    drivers/voltage_mux/README.md
    Documents the background: plan §3 reserves the slot, v2.2 doesn't
    populate it, the two crowbar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
2026-04-24 feat(F2b-3): drivers/hv_charger + hal/pwm + docs/SAFETY.md — SIGNED
    F2b commit 3/4. First commit to touch the HV domain. The driver
    owns the flyback PWM on GP20 and the CHARGED feedback on GP18, with
    a mandatory 60-second auto-disarm built in as a safety net.
    include/hal/pwm.h — lifted from F1's #error stub. Minimal surface:
    hal_pwm_init, hal_pwm_set_freq_duty, hal_pwm_enable,
    hal_pwm_disable, hal_pwm_is_enabled. RP2040-side wraps the
    hardware_pwm + hardware_clocks libs, using the same clkdiv/wrap
    formula as firmware/c/picoemp.c.
    src/rp2040/pwm.c — slice-mask bookkeeping so is_enabled answers
    without querying hardware registers.
    CMakeLists.txt — hal_r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
2026-04-24 feat(F2b-4): drivers/emfi_pulse (CPU-timed) — closes F2b, SIGNED
    F2b commit 4/4. Last driver of F2. The EMFI pulse path drives GP14
    with interrupts disabled for a precisely-timed short pulse, lifting
    the HV cap through the EMFI coil on the SMA.
    Scope decision (documented in the driver header): F2b-4 implements
    CPU-timed manual fire only, by porting firmware/c/picoemp.c
    ::picoemp_pulse verbatim. The sub-µs triggered-fire path, compiled
    as a PIO program coordinated with the trigger compiler and the ADC
    capture ring, is deferred to F4 (glitch_engine/emfi service).
    hal/pio.h stays a #error stub until then. Rationale: PIO state is
    global and stateful — keeping it out of F2 avoids premature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
2026-04-24 docs(skill): update phase-tracking skill to reflect v3.0-f2b closure
    Post-F2b housekeeping.
    State moves from "F2a closed → F2b next" to "F2b closed → F3 next
    (USB composite descriptor)".
    Adds a HAL-state table showing what each header's status is (gpio,
    time, adc, pwm active; pio, dma, usb still #error stubs with their
    target-lift phase noted). Lists all 9 drivers now available. Points
    at the two SIGNED HV commits (f450d43, 69792ac) for future
    reference when the safety-gate rule is invoked again.
    Primes F3 with the critical "16/16 endpoints at the limit" warning
    and the plan's Plan B / Plan C fallbacks. Reminds that F3 is N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
2026-04-24 feat(F3-1): USB composite device — 4× CDC echo, VID:PID 1209:FA17
    F3 commit 1/4. Replaces the pico-sdk stdio_usb default with a
    first-party composite USB device. Scope of this commit:
    * 4× CDC (emfi / crowbar / scanner / target-uart) on IAD.
    * Each CDC echoes received bytes (validation of enumeration +
    bidirectional traffic).
    * VID:PID changes to 1209:FA17 (pid.codes dev range).
    * Serial string derived from the RP2040 unique flash id:
    `FLT3-<16 hex>`.
    * Per-CDC iInterface labels: "FaultyCat EMFI Control",
    "… Crowbar Control", "… Scanner Shell", "… Target UART".
    Vendor IF (CMSIS-DAP v2) lands in F3-2. HID IF (CMSIS-DAP v1) lands
    in F3-3. Full diag migration on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
2026-04-24 feat(usb): magic baud 1200 reboots into BOOTSEL, tools/bootsel.sh
    Follows the pico-sdk stdio_usb convention: the host sets any CDC's
    baud rate to 1200 → the firmware calls `reset_usb_boot()` and jumps
    into the RP2040 bootrom with USB mass-storage mode enabled. Same
    trick `picotool reboot -f -u` uses on stock pico-sdk firmware.
    This closes a long-standing dev-UX friction: the maintainer no
    longer has to physically press BOOTSEL between flashes during the
    tight iterate-build-flash cycle the rewrite relies on.
    usb/src/usb_composite.c
    New `tud_cdc_line_coding_cb(itf, coding)` that checks every CDC's
    newly-set line coding. If `bit_rate == 1200`, `reset_usb_boot(0, 0)`
    drops us to BOOTSE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
2026-04-24 docs(F3): tick status snapshot + PORTING rows for v3.0-f3
    Phase-close hygiene per the live-update policy (memory +
    ARCHITECTURE "Update policy" section). No code change.
    Status snapshot moves from "as of v3.0-f2b / F3 next" to "as of
    v3.0-f3 / F4 next". F3 row flipped to ✓ closed with a one-line
    scope (4×CDC + vendor + HID + magic-baud BOOTSEL + diag on CDC2).
    Tree health enumerated: VID:PID 1209:fa17, 10 interfaces, 16/16
    endpoints, BOS + MS OS 2.0 for Windows, magic-baud reboot.
    Tree diagram:
    * apps/faultycat_fw/main.c row: "diag on CDC2 scanner" (was
    "provisional, F3 moves it").
    * usb/ block expanded to list usb_composite.c + usb_descript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
2026-04-24 docs(skill): update phase-tracking skill to reflect v3.0-f3 closure
    Post-F3 housekeeping.
    State moves from "F2b closed → F3 next" to "F3 closed → F4 next
    (EMFI glitch engine service)".
    F3 row records: VID:PID 1209:FA17, 10 interfaces with 16/16
    endpoints, BOS + MS OS 2.0 for Windows, magic-baud 1200 BOOTSEL,
    diag on CDC2, dap_stub shared between v1 HID + v2 vendor.
    Adds "Estado USB" section showing the composite's current state
    so the next session knows what each interface carries.
    F4 preview lists the two HAL lifts coming (pio.h, dma.h), the
    services/glitch_engine/emfi structure, the PIO compiler
    reimplementation note (f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
2026-04-24 docs(F4): design spec for EMFI glitch engine service
    Single-shot design covering F4-1..F4-6 sub-commits before any code
    lands. Hal/pio + hal/dma lifts, emfi PIO program, ADC capture ring,
    campaign state machine, emfi_proto binary framing, and main.c wiring.
    Includes sub-commit split with explicit HV-signed rows (F4-3 attaches
    PIO to GP14, F4-5 orchestrates the fire path, F4-6 integrates
    top-level). Activates SAFETY.md §3 invariant 5 (HV charged within
    100 ms before PIO fire).
    Non-scope called out explicitly: pre-trigger ADC ring, serial trigger,
    SWD verification, Rust faultycmd, CMSIS-DAP engine — all deferred.
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2026-04-24 feat(F4-1): lift hal/pio — SM/program/FIFO/IRQ + host fake + 11 Unity cases
    RP2040 PIO wrapper behind hal/ so future services (EMFI in F4-3,
    crowbar in F5, SWD in F6, JTAG/UART in F8) stop taking pico-sdk
    hardware/pio.h directly.
    Scope today: program add/remove/clear, SM claim/configure/enable,
    FIFO put/try_get, IRQ get/clear, GPIO->PIO binding, pindirs. pio.h
    contract is small on purpose — extended when later phases demand
    a primitive.
    Host fake records every call for test inspection; push_rx and
    raise_irq let tests simulate PIO->CPU traffic without simulating
    the assembler. 11 Unity cases. Totals now 89 tests / 11 binaries.
    PIO instance allocation convention (documented in ARCHITECT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
2026-04-24 fix(F4-1): address code review — sideset surface, in_pin guard, missing tests
    Code review on 4e8ac97 flagged two latent bugs in hal_pio_sm_cfg_t
    that F4-1's callers don't hit but F5/F6/F8 would:
    - sideset_pin_count was in the struct but only sm_config_set_sideset_pins
    was called, which sets BASE only. SIDESET count/optional/pindirs were
    silently ignored. Fix: add sideset_optional + sideset_pindirs, wire
    sm_config_set_sideset(count, optional, pindirs) before the pins call.
    - in_pin_base = 0 was guarded as "unset" (0 is a valid GPIO — v2.2
    uses GP0 as scanner CH0). Fix: add in_pin_count, guard on count > 0.
    Plus three minor items from the review:
    - test_sm_restart_counts_calls: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
2026-04-24 feat(F4-2): lift hal/dma — claim/configure/ring/DREQ + 8 Unity cases
    Portable RP2040 DMA controller surface for the ADC capture ring
    arriving in F4-4. Kept tight: 12-channel pool, ring-mode config,
    DREQ source, start/abort, busy poll, transfer_count read.
    Fake substitutes the pico-sdk dma_channel_* layer, tracks configure
    fields so tests can assert ring_bits=13 + ring_on_write=true (ie. the
    8 KB ring that emfi_capture will use). DREQ_ADC = 0x24 matches the
    RP2040 datasheet. Totals now 99 tests / 12 binaries.
2026-04-24 feat(F4-3): emfi_pio service + driver PIO attach — first GP14 PIO path
    services/glitch_engine/emfi/emfi_pio.{h,c} — hand-authored PIO
    program compiled per-trigger (IMMEDIATE / EXT_RISING / EXT_FALLING /
    EXT_PULSE_POS). Layout: PULL delay → OUT Y → trigger block →
    JMP Y-- self → PULL width → OUT Y → SET high → JMP Y-- self →
    SET low → IRQ 0. 125 MHz clkdiv → 125 ticks/µs, ~8 ns jitter.
    drivers/emfi_pulse gains emfi_pulse_attach_pio / _detach_pio / _is_
    attached_to_pio. While PIO owns GP14, emfi_pulse_fire_manual returns
    false so the two fire paths can never contend. Detach returns the pin
    to plain-GPIO LOW.
    emfi_pio_deinit also tears down the driver attach, preventi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
2026-04-24 feat(F4-4): emfi_capture — 8 KB ADC DMA ring on GP29 + hal/adc FIFO/DREQ
    services/glitch_engine/emfi/emfi_capture — ADC channel 3 (GP29 /
    target_monitor), 8-bit samples, full-speed ADC, DMA ring-mode
    8192 bytes (ring_bits=13). Start arms DMA from offset 0 and runs
    the ADC; stop aborts DMA and halts ADC. Buffer pointer is stable
    across lifecycle.
    Ported from firmware/c/glitcher/glitcher.c::prepare_adc (FaultyCat
    origin, BSD-3 clean) into the new HAL. hal/adc gains fifo_setup,
    set_clkdiv, run, select_input, fifo_register — the minimum surface
    emfi_capture needs. hal/adc fakes extended with inspectable extra
    state.
    Added emfi_capture_reset_for_test so host unit tests can drop the
    module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
2026-04-24 fix(F4-4): emfi_capture_init calls hal_adc_init for ordering independence
    Code review flagged that emfi_capture_init relied on somebody else
    (e.g. target_monitor_init) having already run hal_adc_init. If F4-5
    orchestration ever calls emfi_capture.init without target_monitor
    being up, the ADC peripheral is unreset and samples are undefined.
    hal_adc_init (underneath: pico-sdk adc_init) is idempotent, so
    calling it here is free and breaks the ordering dependency. Plan
    patched to match.
2026-04-24 feat(F4-5): emfi_campaign state machine + 100ms HV invariant activated
    services/glitch_engine/emfi/emfi_campaign — IDLE→ARMING→CHARGED
    →WAITING→FIRED, with ERROR(HV_NOT_CHARGED|TRIGGER_TIMEOUT|PIO_FAULT
    |BAD_CONFIG) paths. tick() is poll-driven from the main loop;
    fire() is non-blocking; disarm() is a teardown sink that works from
    every state.
    SAFETY.md §3 invariant 5 flipped from "planned for F2b-4" to
    "activated in F4-5". PIO fire is blocked unless hv_charger_is_charged
    was true within EMFI_CAMPAIGN_HV_STALE_MS (100 ms). On miss → ERROR
    + full teardown + hv_charger_disarm.
    Every terminal state (FIRED or ERROR) unconditionally runs:
    emfi_capture_stop → emfi_pio_clear_done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
2026-04-24 feat(F4-6): emfi_proto on CDC0 + main.c integration — closes F4
    services/host_proto/emfi_proto — CRC16-CCITT framing (SOF+CMD+LEN
    +PAYLOAD+CRC). 7 commands: PING/CONFIGURE/ARM/FIRE/DISARM/STATUS/
    CAPTURE. 100 ms inter-byte timeout resets parser. Reply CMD is
    request CMD | 0x80. CRC vector `emfi_proto_crc16("123456789", 9)`
    = 0x29B1 verified in test_crc_known_value.
    apps/faultycat_fw/main.c wires the pump: CDC0 RX → emfi_proto_feed
    → emfi_proto_dispatch → CDC0 TX. emfi_campaign_tick() runs every
    main loop (20 ms cadence). PULSE button stays on CPU fire path
    (F2b); snapshot row on CDC2 now includes EMFI=<STATE>. Banner
    bumped F3 diag → F4 diag.
    usb_composite gains cdc_read; CDC0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
2026-04-24 feat(F5-1): skeleton crowbar service + crowbar_proto stubs
    Lays the directory structure and API headers for the F5 crowbar
    glitch engine, mirroring the EMFI service shape from F4. Bodies are
    intentional stubs — F5-2 (crowbar_pio), F5-3 (crowbar_campaign), and
    F5-4 (crowbar_proto wire-up + main integration) fill them in.
    - services/glitch_engine/crowbar/crowbar_pio.{c,h}
    PIO program API: pio0/SM1, IRQ 1, width_ns range 8..50000,
    delay_us 0..1_000_000. crowbar_out_t selects which gate
    (LP=GP16 or HP=GP17) the PIO drives at fire time.
    - services/glitch_engine/crowbar/crowbar_campaign.{c,h}
    State machine API: IDLE -> ARMING -> ARMED -> WAITING ->
    FIRED|ERROR.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
2026-04-25 feat(F5-2): crowbar_pio — PIO trigger+delay+pulse on pio0/SM1, IRQ 1
    First real F5 service code: a PIO program reimplemented from scratch
    (faultier upstream is unlicensed, see LICENSES/NOTICE-faultier.md)
    that mirrors the EMFI PIO shape but runs on pio0/SM1 and raises IRQ 1
    so the two glitch engines coexist on a single PIO instance.
    Key differences vs services/glitch_engine/emfi/emfi_pio:
    - SM index 1 (EMFI owns SM 0). Allocation frozen at F4-1 in
    docs/ARCHITECTURE.md.
    - IRQ index 1 (EMFI owns IRQ 0). Test asserts the last opcode is
    0xC001 and that raising IRQ 0 does not mark crowbar done.
    - Pulse pin chosen at load time from crowbar_out_t — LP→GP16,
    HP→GP17. CROW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
2026-04-25 feat(F5-3): crowbar_campaign — state machine + break-before-make hand-off
    State machine and gate hand-off between drivers/crowbar_mosfet (idle
    ownership of LP/HP gates) and services/crowbar_pio (PIO ownership
    during the fire window).
    States: IDLE -> ARMED -> WAITING -> FIRED|ERROR. ARMING is reserved
    in the public enum (kept at index 1 for wire-protocol stability) but
    never visited today — arm() validates synchronously and jumps
    straight to ARMED. configure() is the single validation choke point;
    fire() rejects unless state == ARMED so a half-set-up campaign can
    never start the PIO.
    Break-before-make invariant (SAFETY.md §3 #3) is enforced at THREE
    points:
    - arm(): forces crowbar_m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
2026-04-25 docs(F5-5): close F5 — ARCHITECTURE + PORTING snapshot through v3.0-f5
    Live-update of the two phase-tracked docs at the F5 close, per the
    maintenance routine set at v3.0-f2b. Tag `v3.0-f5` is paired with
    this commit so the snapshot matches the etiqueta.
    - Status snapshot header bumps to v3.0-f5; F5 row goes from
    "next" to "✓ closed" with the new SM/IRQ allocation called out
    in the row label; F6 (SWD core) becomes the next phase.
    - Tree health gains a paragraph on services/glitch_engine/crowbar
    + host_proto/crowbar_proto + the removal of the F2b CROWBAR demo
    cycle from main.c.
    - Test count bumps 155 → 212 across 16 → 19 binaries (+19 cases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
